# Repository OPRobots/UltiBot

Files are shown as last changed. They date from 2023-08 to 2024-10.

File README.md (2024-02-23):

# UltiBot

Robot de Minisumo con 6 sensores SHARP GP2Y0E03

<table>
<tr>
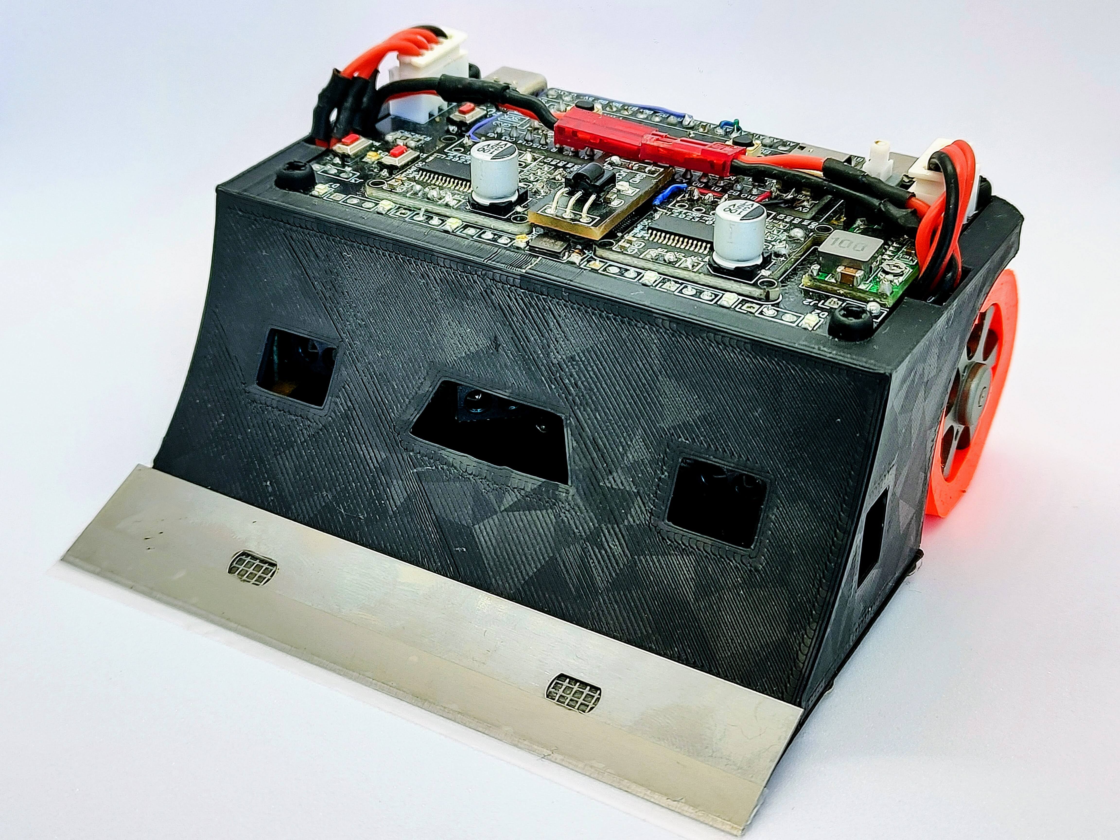
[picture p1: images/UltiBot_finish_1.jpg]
<td  colspan="2">  </td>
</tr>
<tr>
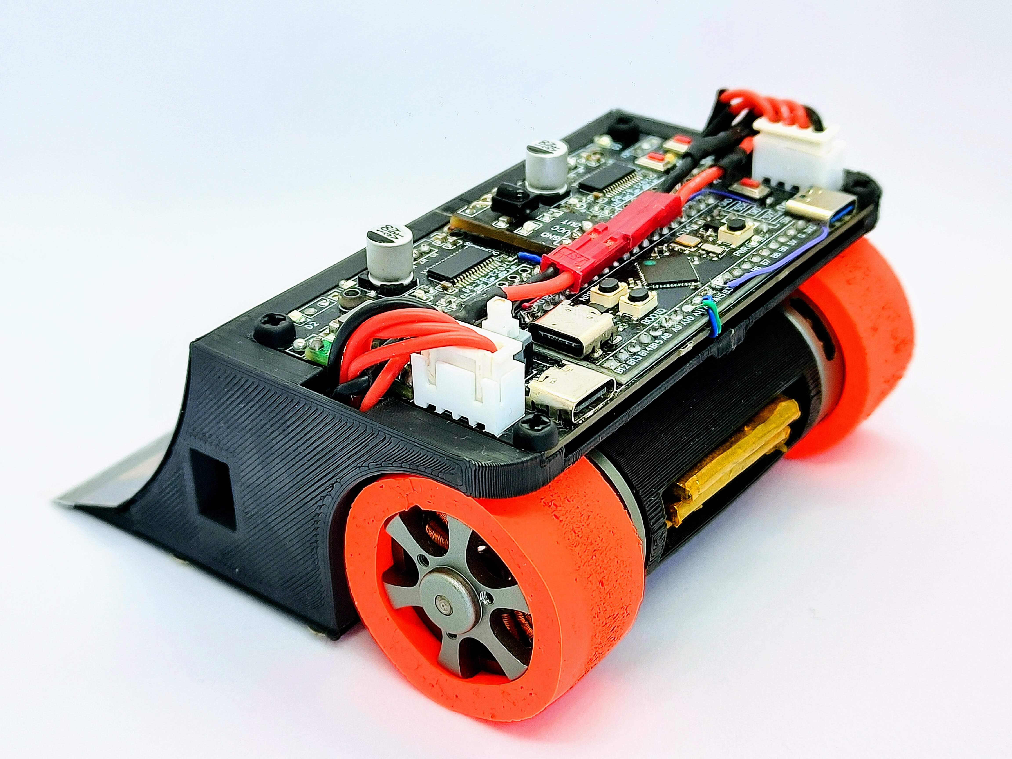
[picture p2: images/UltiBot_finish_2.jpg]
<td>  </td>
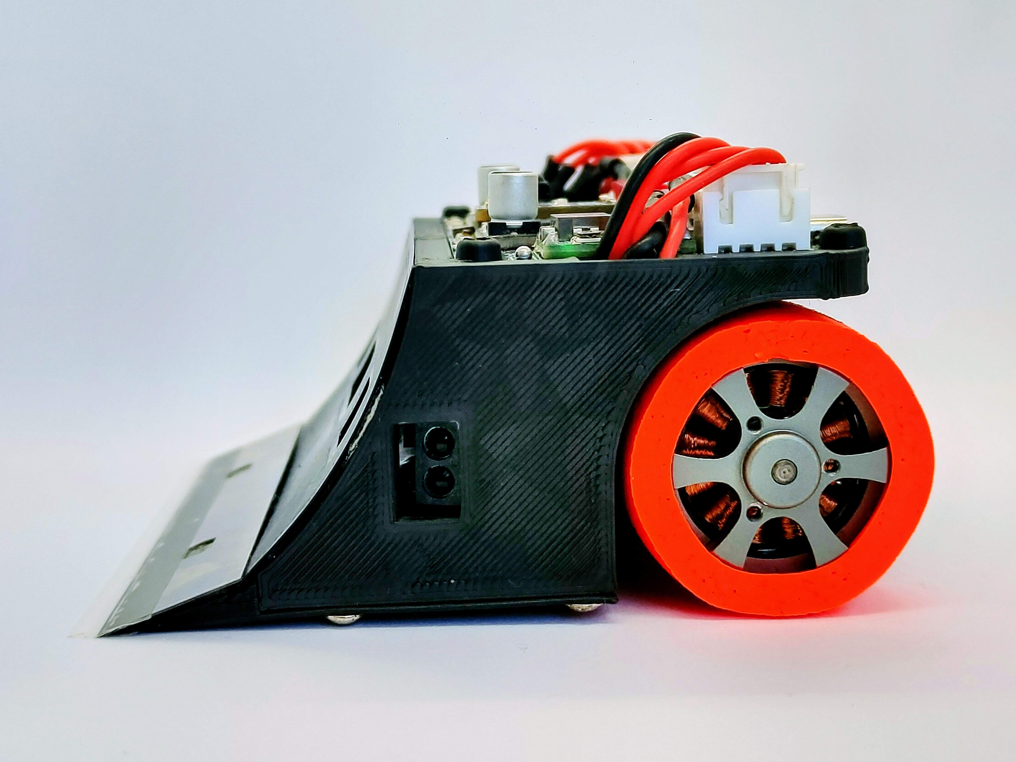
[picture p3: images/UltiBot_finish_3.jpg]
<td>  </td>
</tr>
</table>

## Hardware
- STM32F401CCU6 (Principal) Y STM32F103C8T6 (FOC)
- 2x SimleFOCMini
- 2x Motores gimbal 12v 80T
- 2xLiPo 3S ~180 mAh
- 6x Sensores SHARP GP2Y0E03
- 2x Sensores QRE1113
- Ruedas JSUMO JS2622
- Chasis impreso en PLA

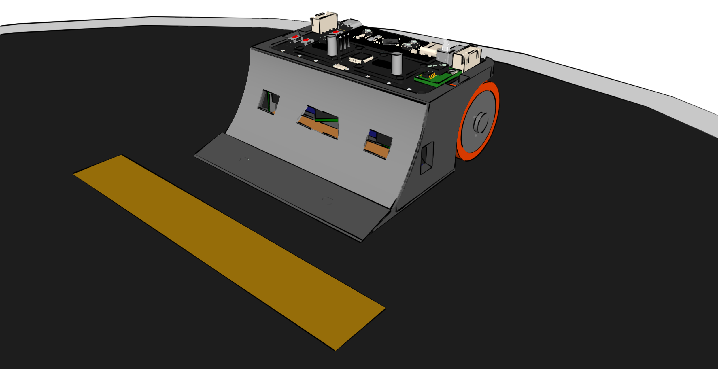
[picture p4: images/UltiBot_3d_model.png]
UltiBot Chasis UltiBot - Chasis


## Software
- Programado con VSCode y PlatformIO
- Disponible programa con estrategias básicas

## KiCAD

### PCB UltiBot v1.0
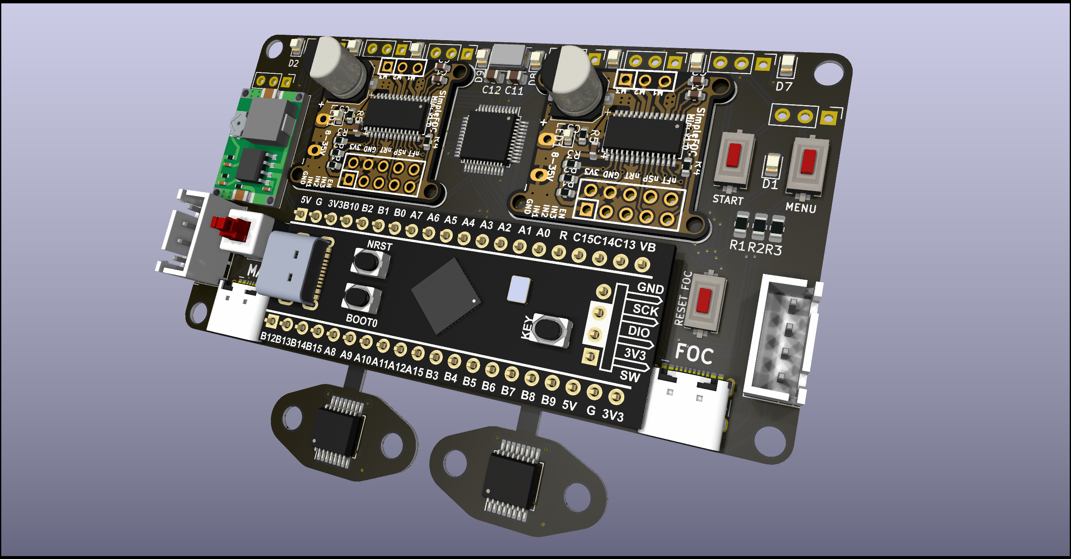
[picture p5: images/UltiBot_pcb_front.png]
UltiBot PCB Front UltiBot - Chasis
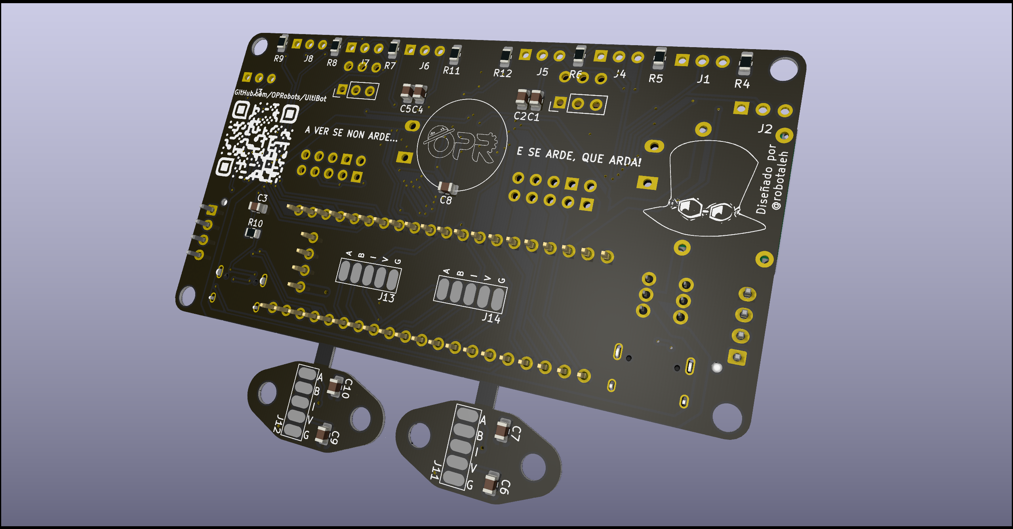
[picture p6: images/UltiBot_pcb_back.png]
UltiBot PCB Back UltiBot - Chasis


### Librerías

Las librerías necesarias para este proyecto se encuentran en [OPRobots/KiCADLibraries](https://github.com/OPRobots/KiCADLibraries)

La estructura tiene que quedar de la siguiente forma:

```bash
└── kicad_project
    └── custom_libraries
        ├── custom_footprints
        │   ├── *.kicad_mod
        │   └── ...
        └── custom_symbols.kicad_sym
```

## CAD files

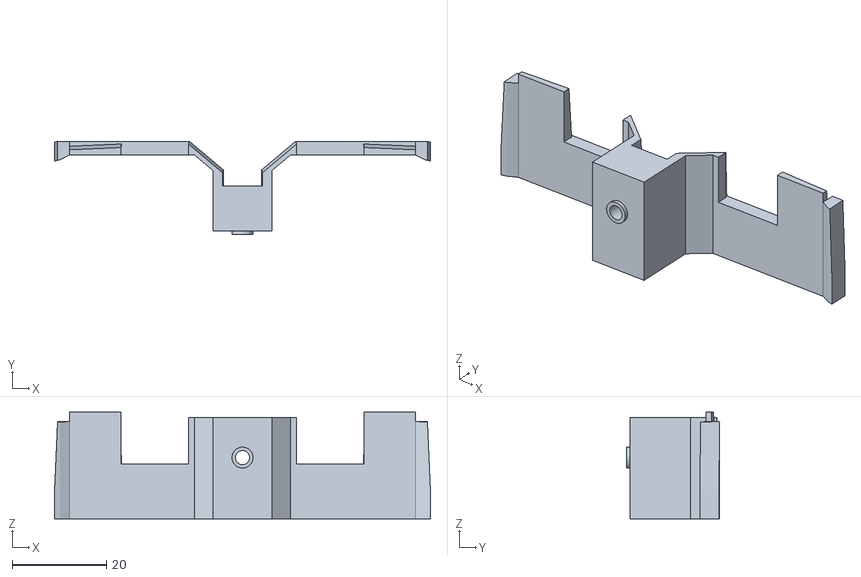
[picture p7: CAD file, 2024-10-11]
3d_model/stl_files/sensor_v2.stl
79.8 x 19.8 x 22.7

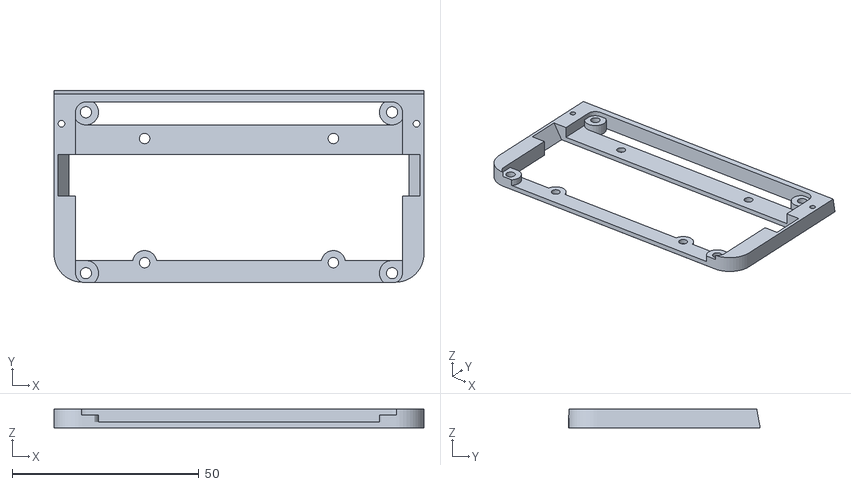
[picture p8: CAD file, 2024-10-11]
3d_model/stl_files/top_v2.stl
99.0 x 51.2 x 5.00

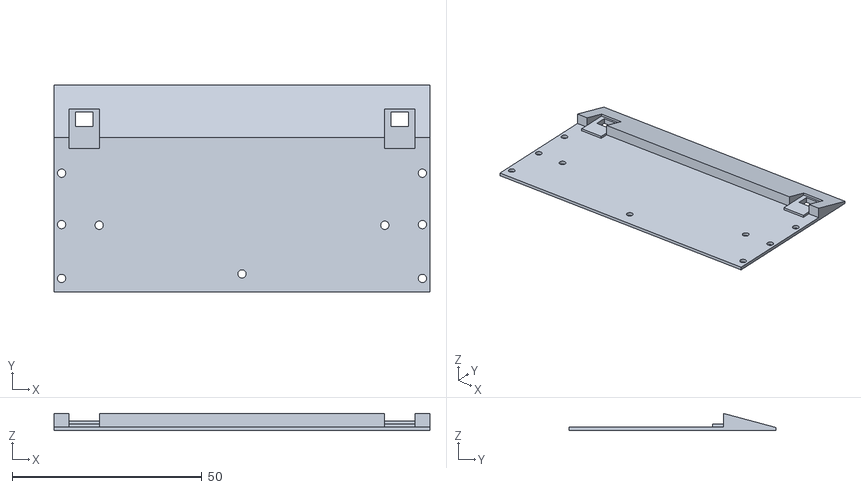
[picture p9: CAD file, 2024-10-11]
3d_model/stl_files/base_v2.stl
99.0 x 54.6 x 4.52

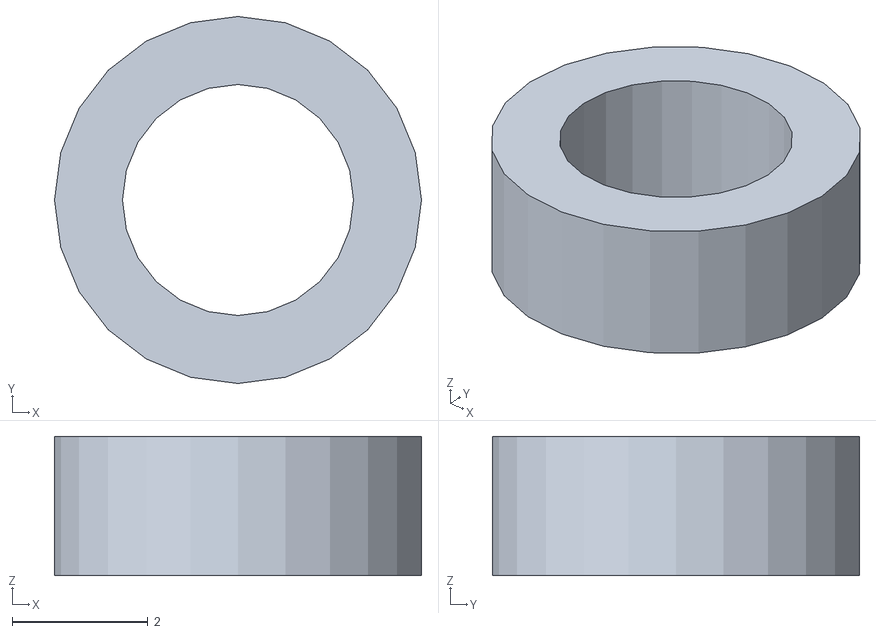
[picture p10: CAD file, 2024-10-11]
3d_model/stl_files/spacer_v2.stl
5.40 x 5.40 x 2.05

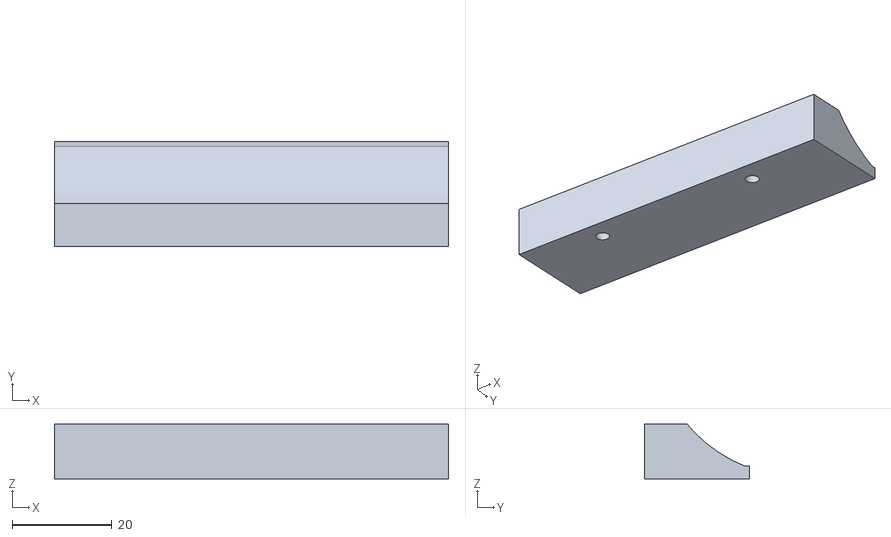
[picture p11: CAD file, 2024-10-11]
3d_model/stl_files/molde_plomo.stl
79.0 x 21.0 x 11.0

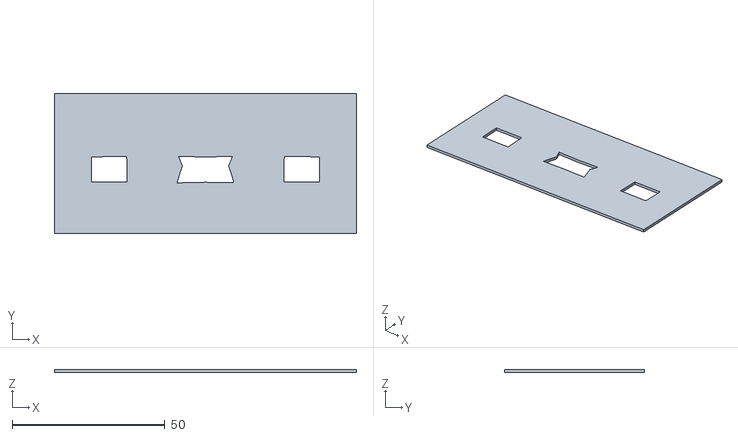
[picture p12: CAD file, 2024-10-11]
3d_model/stl_files/ramp_v2.stl
99.0 x 45.8 x 1.00

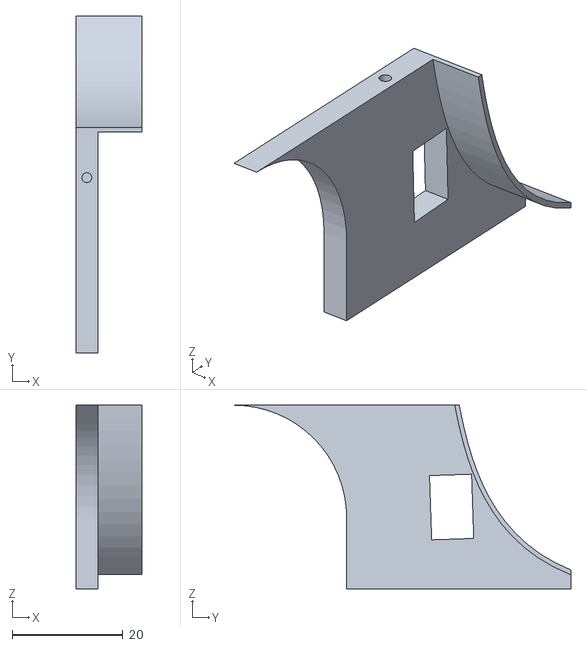
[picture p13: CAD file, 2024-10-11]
3d_model/stl_files/side_v2.stl
12.0 x 60.9 x 33.1

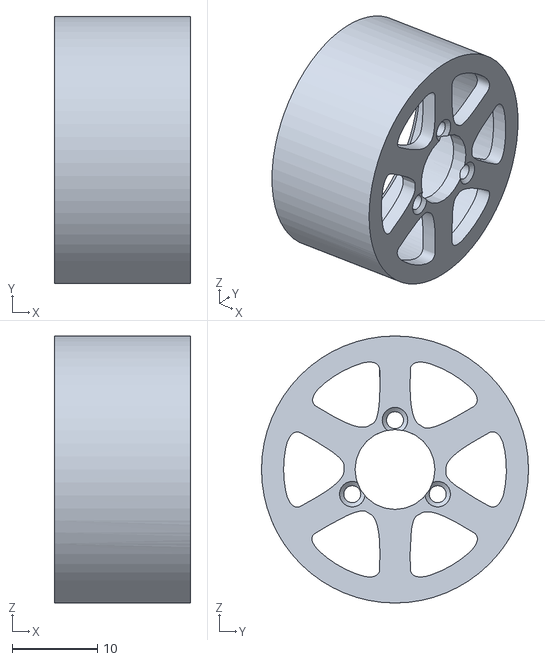
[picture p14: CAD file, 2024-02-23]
3d_model/stl_files/wheel_v2.stl
16.0 x 31.4 x 31.4

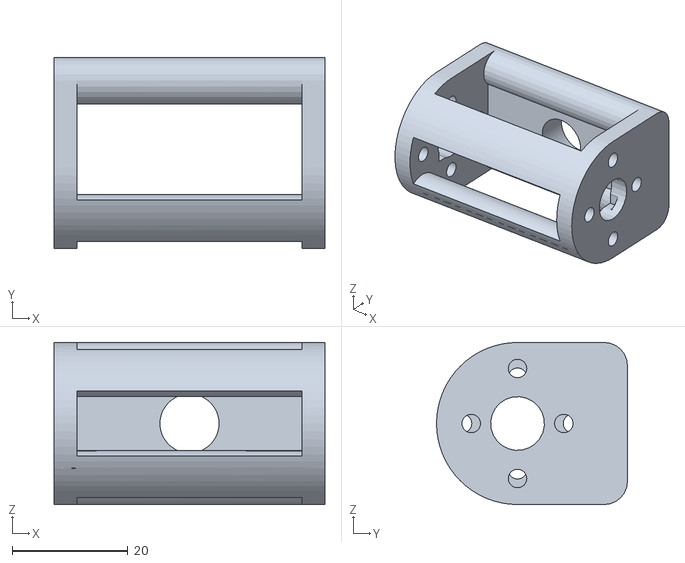
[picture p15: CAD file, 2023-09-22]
3d_model/stl_files/motors.stl
46.8 x 33.0 x 28.0

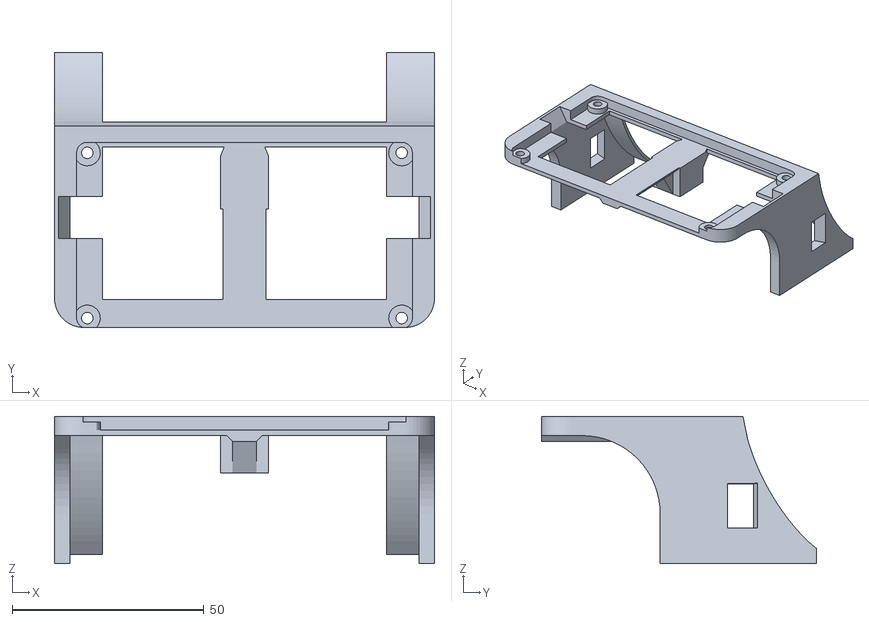
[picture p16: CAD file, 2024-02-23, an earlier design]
3d_model/stl_files/top.stl
99.0 x 71.6 x 38.3

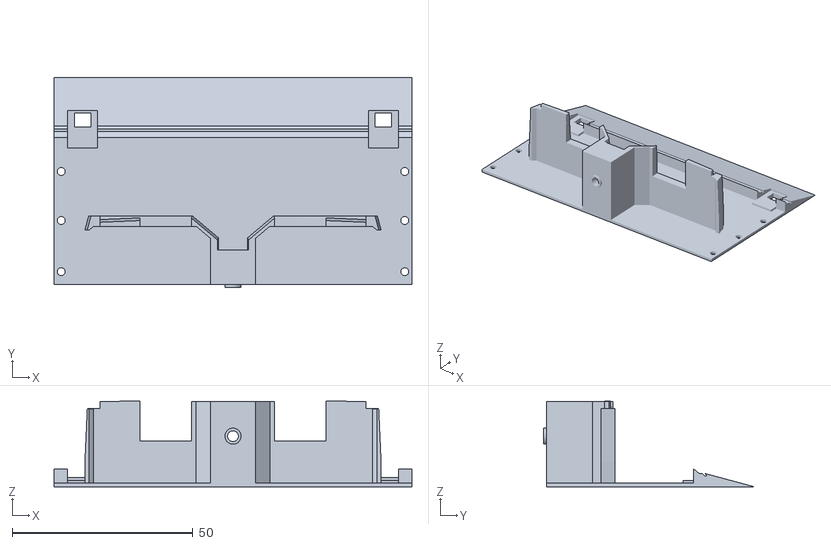
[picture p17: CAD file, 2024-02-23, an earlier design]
3d_model/stl_files/base.stl
99.0 x 58.0 x 23.7

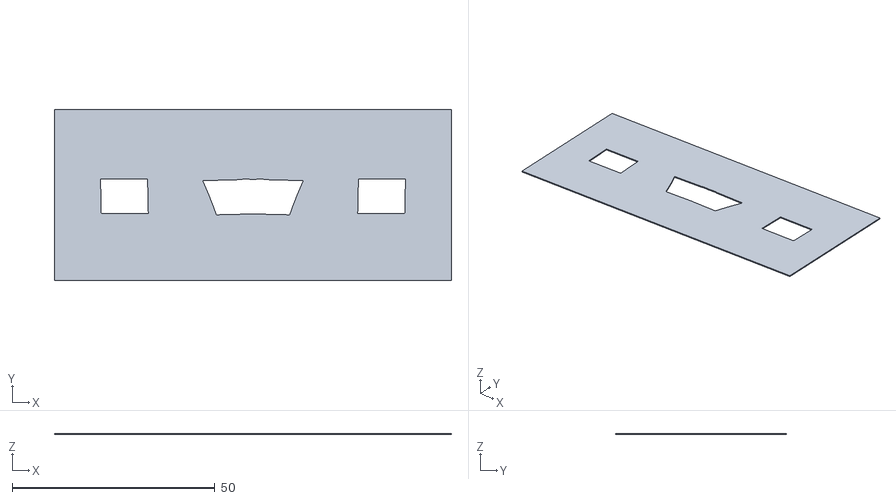
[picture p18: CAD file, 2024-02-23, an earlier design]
3d_model/stl_files/ramp.stl
98.0 x 42.2 x 0.302

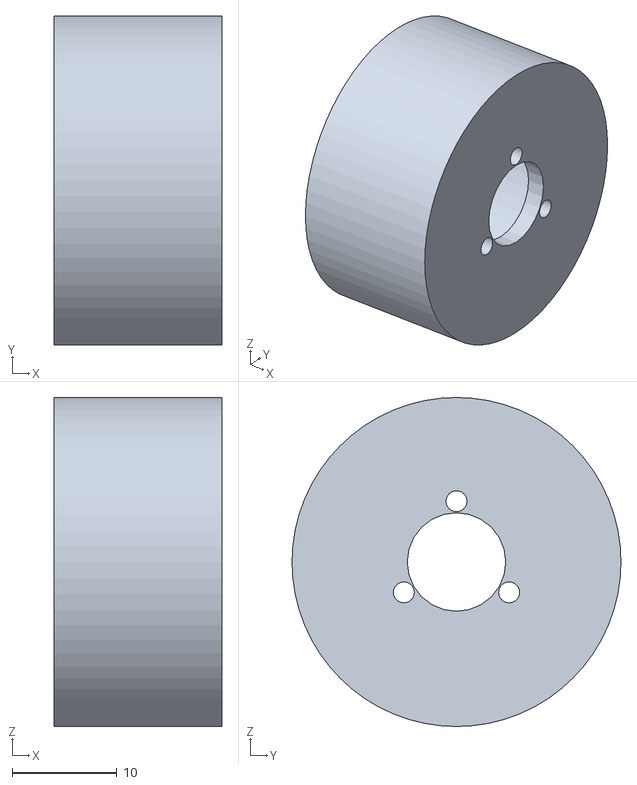
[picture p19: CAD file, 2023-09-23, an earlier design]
3d_model/stl_files/wheel.stl
16.0 x 31.4 x 31.4

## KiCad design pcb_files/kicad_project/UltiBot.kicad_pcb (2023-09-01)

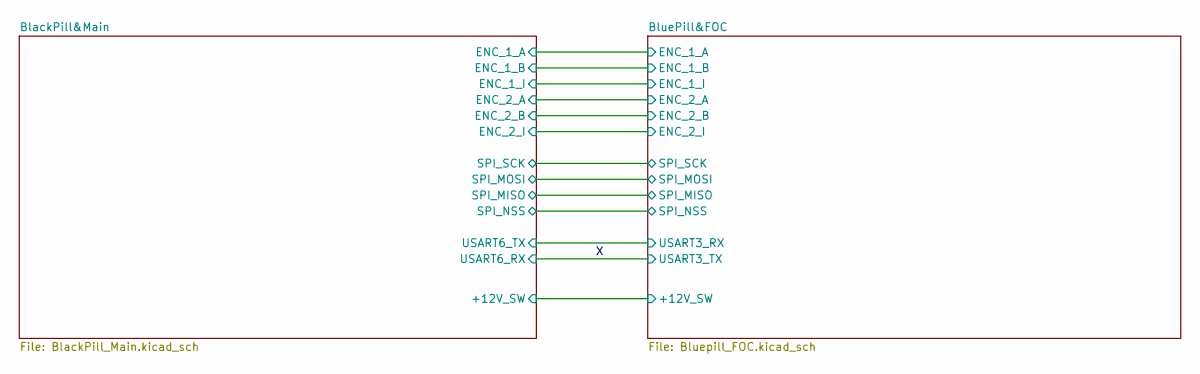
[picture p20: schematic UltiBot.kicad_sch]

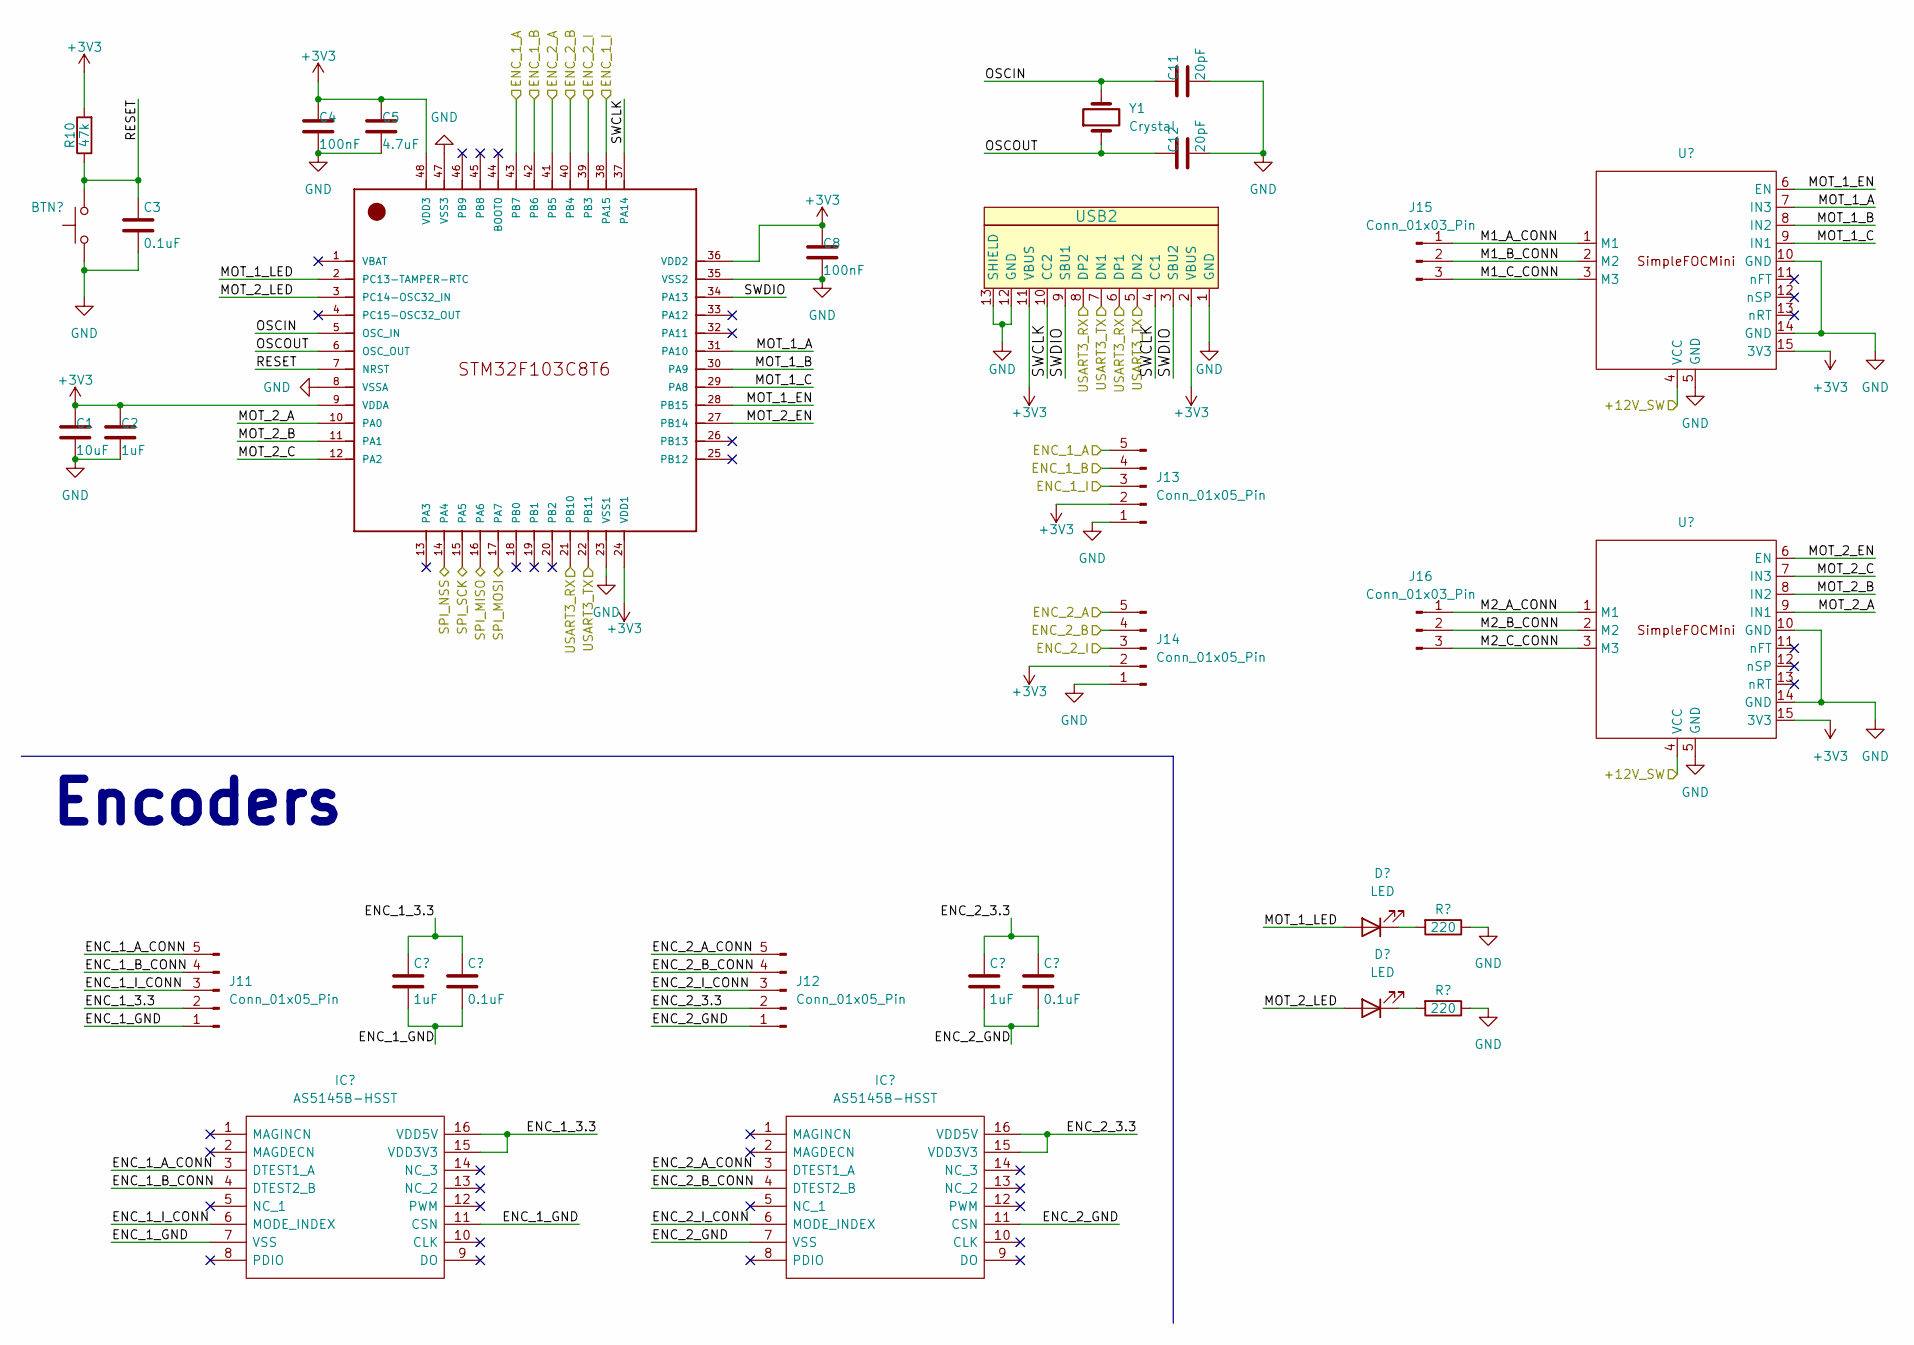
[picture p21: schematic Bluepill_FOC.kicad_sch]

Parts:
BTN3: SW_SPST_EVQPE1
C1: 10uF; C_0805_2012Metric
C2, C6, C9: 1uF; C_0805_2012Metric
C3, C7, C10: 0.1uF; C_0805_2012Metric
C4, C8: 100nF; C_0805_2012Metric
C5: 4.7uF; C_0805_2012Metric
C11, C12: 20pF; C_0805_2012Metric
D8, D9: LED; LED_0805_2012Metric
IC1, IC2: AS5145B-HSST; SSOP-16_5.3x6.2mm_P0.65mm
J11, J12, J13, J14: Conn_01x05_Pin; 1x05 Pad
J15, J16: Conn_01x03_Pin; PinHeader_1x03_P2.54mm_Vertical
R10: 47k; R_0805_2012Metric
R11, R12: 220; R_0805_2012Metric_Pad1.20x1.40mm_HandSolder
U2: BluePill; LQFP-48_7x7mm_P0.5mm
U3, U4: SimpleFOCMini
USB2: USB-C ST-Link USART
Y1: Crystal; Crystal_SMD_5032-2Pin_5.0x3.2mm

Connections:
+3V3: C1.1, C2.1, C4.1, C5.1, C8.1, J13.2, J14.2, R10.2, U2.9 (VDDA), U2.24 (VDD1), U2.36 (VDD2), U2.48 (VDD3), U3.15 (3V3), U4.15 (3V3), USB2.2 (VBUS), USB2.11 (VBUS); also elsewhere on the board
/BlackPill&Main/+12V_SW: U3.4 (VCC), U4.4 (VCC); also elsewhere on the board
/BlackPill&Main/ENC_1_A: J13.5, U2.43 (PB7); also elsewhere on the board
/BlackPill&Main/ENC_1_B: J13.4, U2.42 (PB6); also elsewhere on the board
/BlackPill&Main/ENC_1_I: J13.3, U2.38 (PA15); also elsewhere on the board
/BlackPill&Main/ENC_2_A: J14.5, U2.41 (PB5); also elsewhere on the board
/BlackPill&Main/ENC_2_B: J14.4, U2.40 (PB4); also elsewhere on the board
/BlackPill&Main/ENC_2_I: J14.3, U2.39 (PB3); also elsewhere on the board
/BlackPill&Main/SPI_MISO: U2.16 (PA6); also elsewhere on the board
/BlackPill&Main/SPI_MOSI: U2.17 (PA7); also elsewhere on the board
/BlackPill&Main/SPI_NSS: U2.14 (PA4); also elsewhere on the board
/BlackPill&Main/SPI_SCK: U2.15 (PA5); also elsewhere on the board
/BlackPill&Main/USART6_RX: U2.22 (PB11), USB2.5 (DN2), USB2.7 (DN1); also elsewhere on the board
/BlackPill&Main/USART6_TX: U2.21 (PB10), USB2.6 (DP1), USB2.8 (DP2); also elsewhere on the board
/BluePill&FOC/ENC_1_3.3: C6.1, C7.1, IC1.15 (VDD3V3), IC1.16 (VDD5V), J11.2
/BluePill&FOC/ENC_1_A_CONN: IC1.3 (DTEST1_A), J11.5
/BluePill&FOC/ENC_1_B_CONN: IC1.4 (DTEST2_B), J11.4
/BluePill&FOC/ENC_1_GND: C6.2, C7.2, IC1.7 (VSS), IC1.11 (CSN), J11.1
/BluePill&FOC/ENC_1_I_CONN: IC1.6 (MODE_INDEX), J11.3
/BluePill&FOC/ENC_2_3.3: C9.1, C10.1, IC2.15 (VDD3V3), IC2.16 (VDD5V), J12.2
/BluePill&FOC/ENC_2_A_CONN: IC2.3 (DTEST1_A), J12.5
/BluePill&FOC/ENC_2_B_CONN: IC2.4 (DTEST2_B), J12.4
/BluePill&FOC/ENC_2_GND: C9.2, C10.2, IC2.7 (VSS), IC2.11 (CSN), J12.1
/BluePill&FOC/ENC_2_I_CONN: IC2.6 (MODE_INDEX), J12.3
/BluePill&FOC/M1_A_CONN: J15.1, U3.1 (M1)
/BluePill&FOC/M1_B_CONN: J15.2, U3.2 (M2)
/BluePill&FOC/M1_C_CONN: J15.3, U3.3 (M3)
/BluePill&FOC/M2_A_CONN: J16.1, U4.1 (M1)
/BluePill&FOC/M2_B_CONN: J16.2, U4.2 (M2)
/BluePill&FOC/M2_C_CONN: J16.3, U4.3 (M3)
/BluePill&FOC/MOT_1_A: U2.31 (PA10), U3.7 (IN3)
/BluePill&FOC/MOT_1_B: U2.30 (PA9), U3.8 (IN2)
/BluePill&FOC/MOT_1_C: U2.29 (PA8), U3.9 (IN1)
/BluePill&FOC/MOT_1_EN: U2.28 (PB15), U3.6 (EN)
/BluePill&FOC/MOT_1_LED: D8.2 (A), U2.2 (PC13-TAMPER-RTC)
/BluePill&FOC/MOT_2_A: U2.10 (PA0), U4.9 (IN1)
/BluePill&FOC/MOT_2_B: U2.11 (PA1), U4.8 (IN2)
/BluePill&FOC/MOT_2_C: U2.12 (PA2), U4.7 (IN3)
/BluePill&FOC/MOT_2_EN: U2.27 (PB14), U4.6 (EN)
/BluePill&FOC/MOT_2_LED: D9.2 (A), U2.3 (PC14-OSC32_IN)
/BluePill&FOC/OSCIN: C11.1, U2.5 (OSC_IN), Y1.2
/BluePill&FOC/OSCOUT: C12.1, U2.6 (OSC_OUT), Y1.1
/BluePill&FOC/RESET: BTN3.2, C3.1, R10.1, U2.7 (NRST)
/BluePill&FOC/SWCLK: U2.37 (PA14), USB2.4 (CC1), USB2.10 (CC2)
/BluePill&FOC/SWDIO: U2.34 (PA13), USB2.3 (SBU2), USB2.9 (SBU1)
GND: BTN3.1, C1.2, C2.2, C3.2, C4.2, C5.2, C8.2, C11.2, C12.2, J13.1, J14.1, R11.1, R12.1, U2.8 (VSSA), U2.23 (VSS1), U2.35 (VSS2), U2.47 (VSS3), U3.5 (GND), U3.10 (GND), U3.14 (GND), U4.5 (GND), U4.10 (GND), U4.14 (GND), USB2.1 (GND), USB2.12 (GND), USB2.13 (SHIELD); also elsewhere on the board
unnamed: D8.1 (K), R11.2
unnamed: D9.1 (K), R12.2

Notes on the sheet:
Encoders

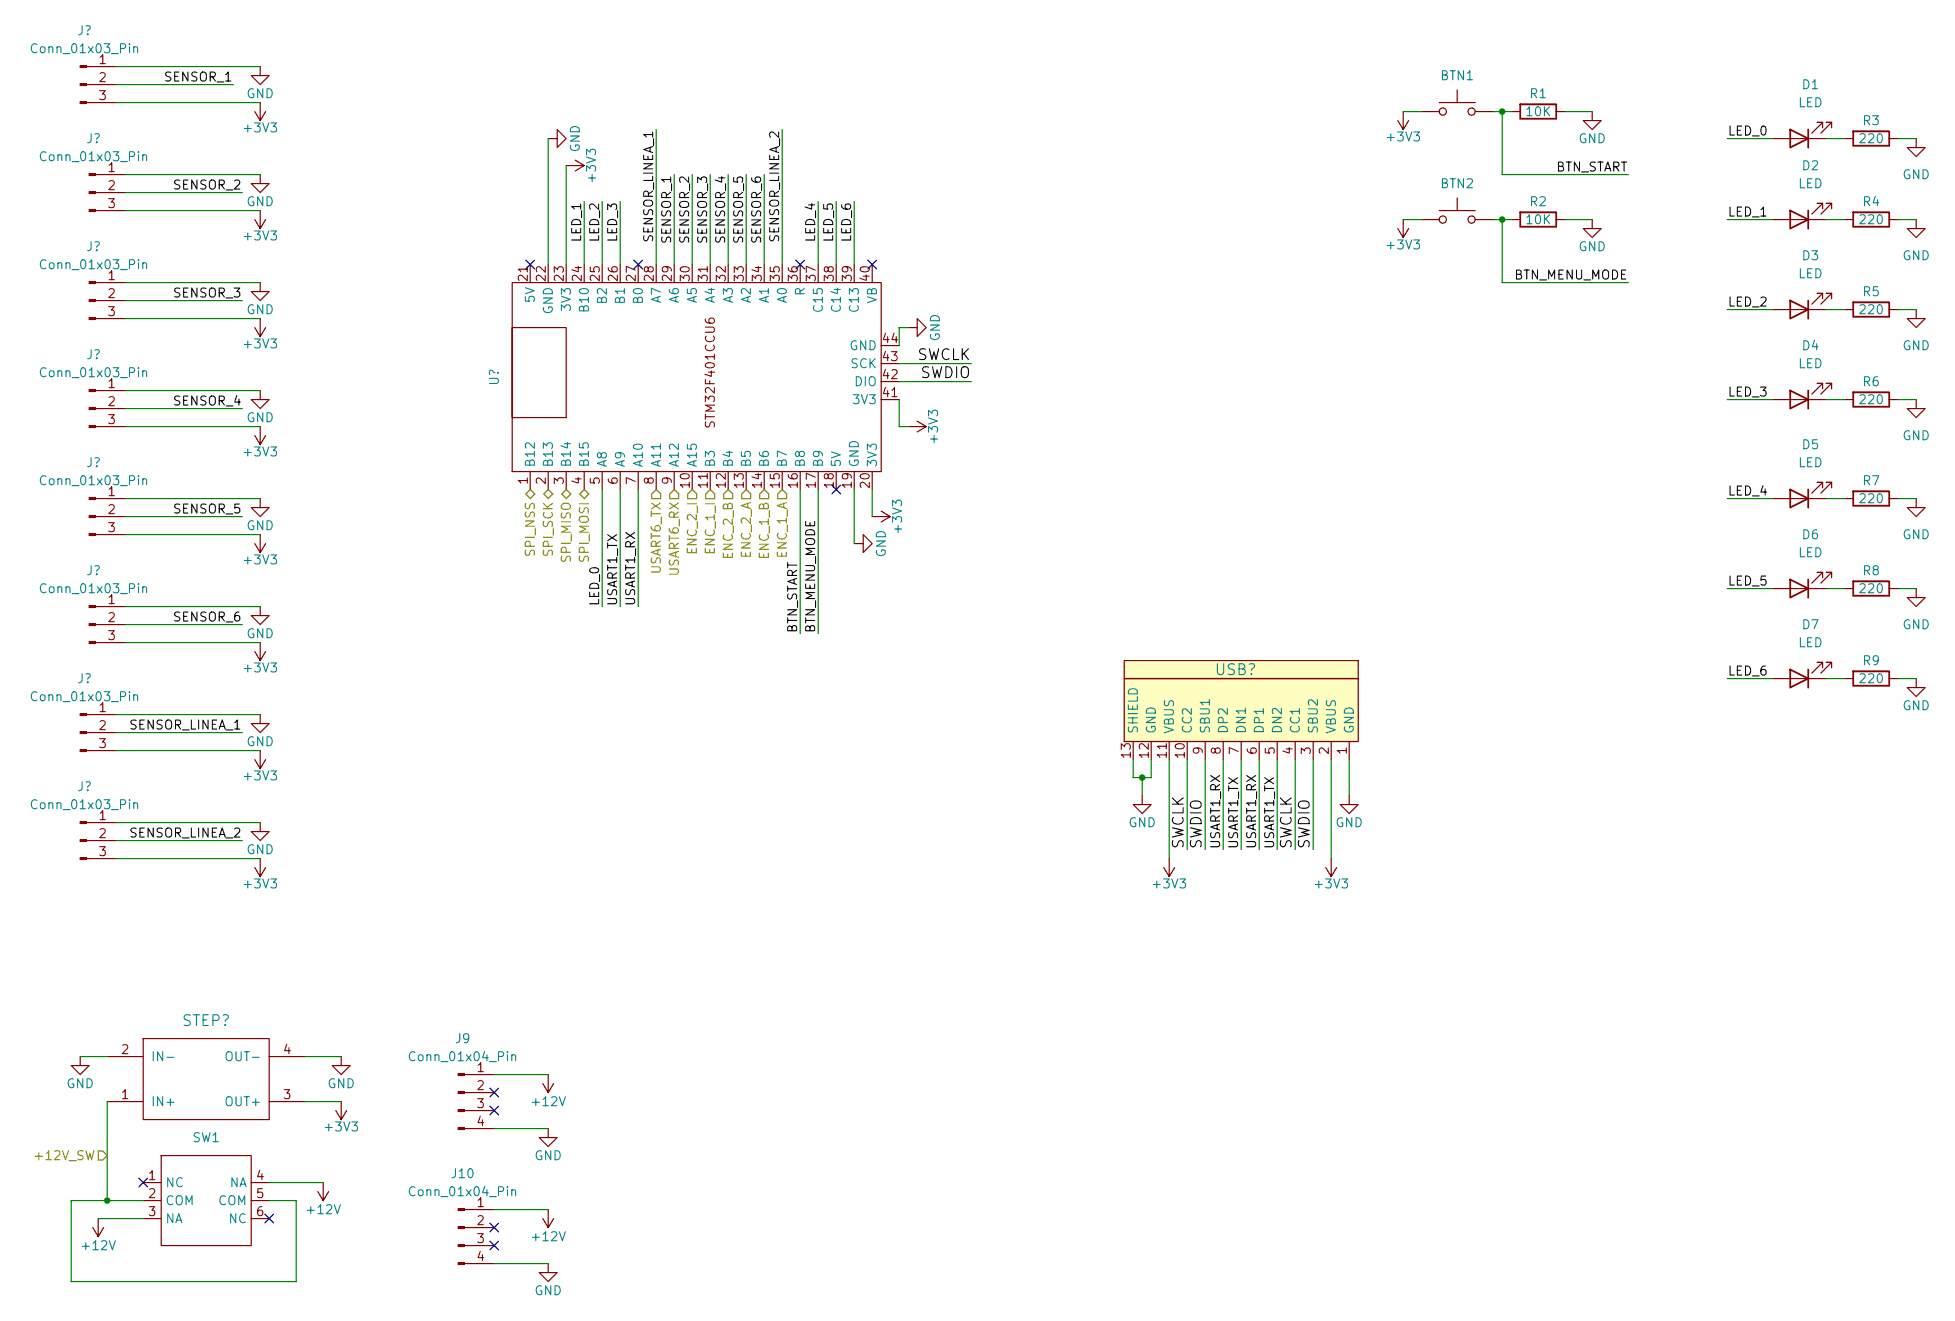
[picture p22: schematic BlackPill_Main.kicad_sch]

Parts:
BTN1, BTN2: SW_SPST_EVQPE1
D1, D2, D3, D4, D5, D6, D7: LED; LED_0805_2012Metric
J1, J2, J3, J4, J5, J6, J7, J8: Conn_01x03_Pin; PinHeader_1x03_P2.54mm_Vertical
J9, J10: Conn_01x04_Pin; JST_XH_B4B-XH-AM_1x04_P2.50mm_Vertical
R1, R2: 10K; R_0805_2012Metric_Pad1.20x1.40mm_HandSolder
R3, R4, R5, R6, R7, R8, R9: 220; R_0805_2012Metric_Pad1.20x1.40mm_HandSolder
STEP1: Mini360
SW1: Switch6P
U1: BlackPill_STM32F401
USB1: USB-C ST-Link USART

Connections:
+3V3: BTN1.1, BTN2.1, J1.3, J2.3, J3.3, J4.3, J5.3, J6.3, J7.3, J8.3, STEP1.3 (OUT+), U1.20 (3V3), U1.23 (3V3), U1.41 (3V3), USB1.2 (VBUS), USB1.11 (VBUS); also elsewhere on the board
+12V: J9.1, J10.1, SW1.3 (NA), SW1.4 (NA); also elsewhere on the board
/BlackPill&Main/+12V_SW: STEP1.1 (IN+), SW1.2 (COM), SW1.5 (COM); also elsewhere on the board
/BlackPill&Main/BTN_MENU_MODE: BTN2.2, R2.2, U1.17 (B9)
/BlackPill&Main/BTN_START: BTN1.2, R1.2, U1.16 (B8)
/BlackPill&Main/ENC_1_A: U1.15 (B7); also elsewhere on the board
/BlackPill&Main/ENC_1_B: U1.14 (B6); also elsewhere on the board
/BlackPill&Main/ENC_1_I: U1.11 (B3); also elsewhere on the board
/BlackPill&Main/ENC_2_A: U1.13 (B5); also elsewhere on the board
/BlackPill&Main/ENC_2_B: U1.12 (B4); also elsewhere on the board
/BlackPill&Main/ENC_2_I: U1.10 (A15); also elsewhere on the board
/BlackPill&Main/LED_0: D1.2 (A), U1.5 (A8)
/BlackPill&Main/LED_1: D2.2 (A), U1.24 (B10)
/BlackPill&Main/LED_2: D3.2 (A), U1.25 (B2)
/BlackPill&Main/LED_3: D4.2 (A), U1.26 (B1)
/BlackPill&Main/LED_4: D5.2 (A), U1.37 (C15)
/BlackPill&Main/LED_5: D6.2 (A), U1.38 (C14)
/BlackPill&Main/LED_6: D7.2 (A), U1.39 (C13)
/BlackPill&Main/SENSOR_1: J1.2, U1.29 (A6)
/BlackPill&Main/SENSOR_2: J4.2, U1.30 (A5)
/BlackPill&Main/SENSOR_3: J5.2, U1.31 (A4)
/BlackPill&Main/SENSOR_4: J6.2, U1.32 (A3)
/BlackPill&Main/SENSOR_5: J7.2, U1.33 (A2)
/BlackPill&Main/SENSOR_6: J8.2, U1.34 (A1)
/BlackPill&Main/SENSOR_LINEA_1: J2.2, U1.28 (A7)
/BlackPill&Main/SENSOR_LINEA_2: J3.2, U1.35 (A0)
/BlackPill&Main/SPI_MISO: U1.3 (B14); also elsewhere on the board
/BlackPill&Main/SPI_MOSI: U1.4 (B15); also elsewhere on the board
/BlackPill&Main/SPI_NSS: U1.1 (B12); also elsewhere on the board
/BlackPill&Main/SPI_SCK: U1.2 (B13); also elsewhere on the board
/BlackPill&Main/SWCLK: U1.43 (SCK), USB1.4 (CC1), USB1.10 (CC2)
/BlackPill&Main/SWDIO: U1.42 (DIO), USB1.3 (SBU2), USB1.9 (SBU1)
/BlackPill&Main/USART1_RX: U1.7 (A10), USB1.6 (DP1), USB1.8 (DP2)
/BlackPill&Main/USART1_TX: U1.6 (A9), USB1.5 (DN2), USB1.7 (DN1)
/BlackPill&Main/USART6_RX: U1.9 (A12); also elsewhere on the board
/BlackPill&Main/USART6_TX: U1.8 (A11); also elsewhere on the board
GND: J1.1, J2.1, J3.1, J4.1, J5.1, J6.1, J7.1, J8.1, J9.4, J10.4, R1.1, R2.1, R3.1, R4.1, R5.1, R6.1, R7.1, R8.1, R9.1, STEP1.2 (IN-), STEP1.4 (OUT-), U1.19 (GND), U1.22 (GND), U1.44 (GND), USB1.1 (GND), USB1.12 (GND), USB1.13 (SHIELD); also elsewhere on the board
unnamed: D1.1 (K), R3.2
unnamed: D2.1 (K), R4.2
unnamed: D3.1 (K), R5.2
unnamed: D4.1 (K), R6.2
unnamed: D5.1 (K), R7.2
unnamed: D6.1 (K), R8.2
unnamed: D7.1 (K), R9.2

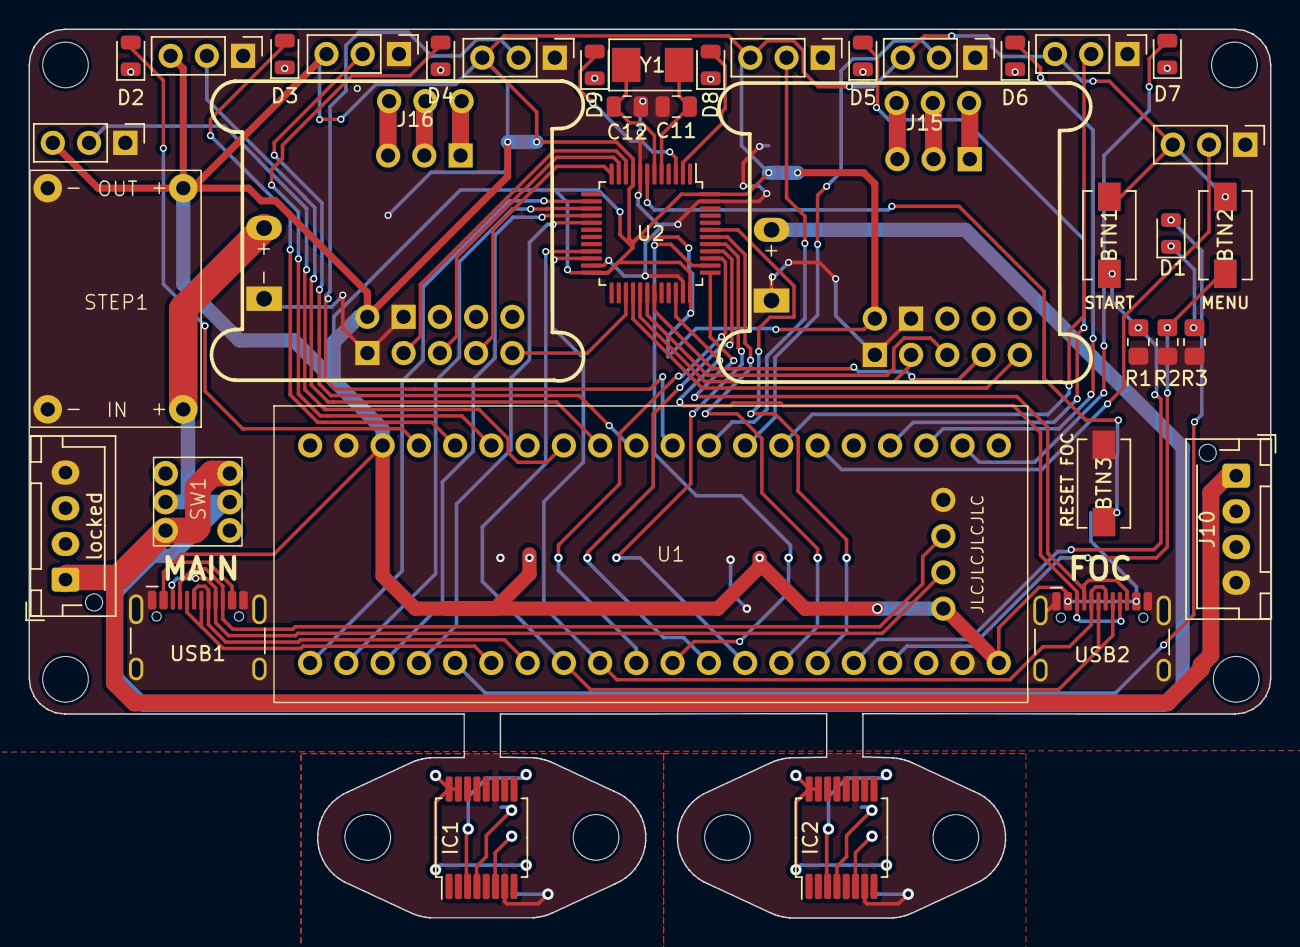
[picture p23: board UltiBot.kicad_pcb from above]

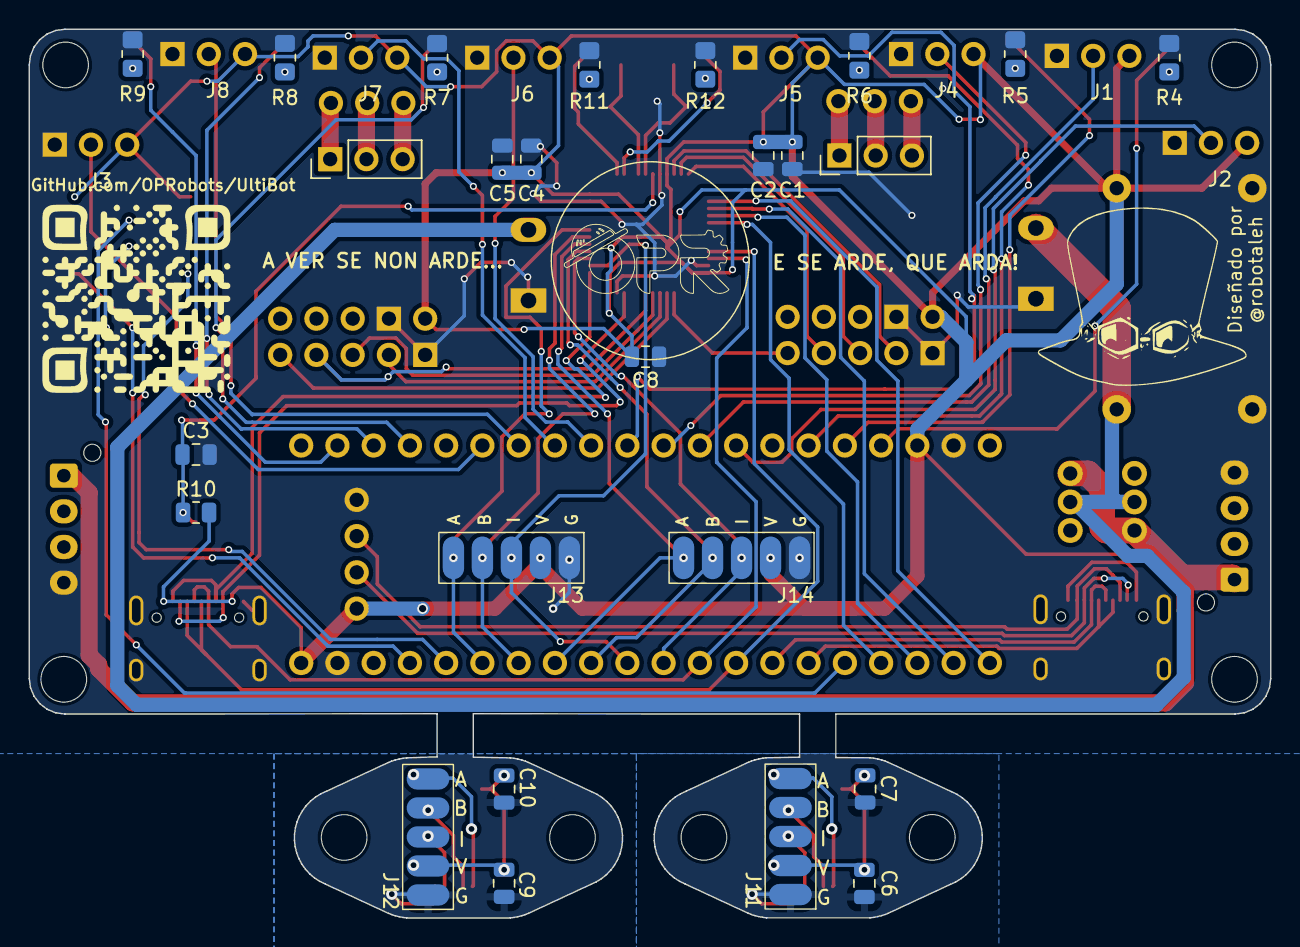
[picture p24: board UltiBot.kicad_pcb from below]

Board: 2 copper layers, 87.0 x 62.3 mm, 63 parts (25 on the bottom side), 77 nets.

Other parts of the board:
locked: Conn_01x04_Pin; JST - XH - Thru (V) - 4Pin - 2.54mm

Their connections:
+12V: locked.1; also elsewhere on the board
GND: locked.4; also elsewhere on the board

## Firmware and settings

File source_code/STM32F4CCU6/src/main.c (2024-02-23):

#include "command.h"
#include "config.h"
#include "control.h"
#include "debug.h"
#include "delay.h"
#include "leds.h"
#include "menu.h"
#include "motors.h"
#include "sensors.h"
#include "setup.h"
#include "usart.h"
#include "eeprom.h"
#include "rc5.h"

void sys_tick_handler(void) {
  clock_tick();
  update_sensors_readings();
}

int main(void) {
  setup();
  eeprom_load();
  rc5_init();

  while (true) {
    // debug_sensors_leds();
    // debug_sensors_raw();
    // // debug_sensors_position();
    // // printf("%d - %d\n", get_sensor_digital(SENSOR_LINE_LEFT), get_sensor_digital(SENSOR_LINE_RIGHT));
    // // // // // printf("%d\n", get_sensor_filtered(SENSOR_FRONT_LEFT));
    // // delay(25);

    // // send_command(CMD_MOTOR_SPEED_RIGHT, 40);
    // // send_command(CMD_MOTOR_SPEED_LEFT, 40);
    // // send_command(CMD_MOTOR_ENABLE, 0);
    // // delay(15000);
    // // send_command(CMD_MOTOR_SPEED_RIGHT, 0);
    // // send_command(CMD_MOTOR_SPEED_LEFT, 0);
    // // send_command(CMD_MOTOR_DISABLE, 0);
    // // delay(2000);

    // // if (get_start_btn()) {
    // //   send_command(CMD_MOTOR_DISABLE, 0);
    // //   send_command(CMD_MOTOR_SPEED_RIGHT, 40);
    // //   send_command(CMD_MOTOR_SPEED_LEFT, 40);
    // // } else {
    // //   send_command(CMD_MOTOR_ENABLE, 0);
    // //   send_command(CMD_MOTOR_SPEED_RIGHT, 20);
    // //   send_command(CMD_MOTOR_SPEED_LEFT, 20);
    // // }
    // // printf("pato\n");
    // // printf("%ld\n", get_us_counter());
    // delay(100);

    // continue;

    if (!is_competicion_iniciada() && !is_competicion_iniciando()) {
      check_menu_button();
      // debug_sensors_leds();
      if (get_start_btn()) {
        set_sensor_led(false);
        set_menu_led(false);
        while (get_start_btn()) {
          set_sensor_led_waiting(100);
        }
        set_competicion_iniciando(true);
      }
    } else if (is_competicion_iniciando()) {
      uint32_t millisInicio = get_clock_ticks();
      while (get_clock_ticks() < (millisInicio + get_start_millis()) && is_competicion_iniciando()) {
        set_sensor_led_starting(millisInicio);
      }
      if (is_competicion_iniciando()) {
        set_sensor_led(false);
        set_competicion_iniciada(true);
        send_command(CMD_MOTOR_ENABLE, 0);
      }
    } else {
      debug_sensors_leds();
      control_main_loop();
    }
  }
  return 0;
}

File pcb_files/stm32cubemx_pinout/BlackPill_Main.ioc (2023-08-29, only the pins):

Mcu.UserName=STM32F401CCUx
PA0-WKUP.Signal=ADCx_IN0
PA1.Signal=ADCx_IN1
PA10.Signal=USART1_RX
PA11.Signal=USART6_TX
PA12.Signal=USART6_RX
PA13.Signal=SYS_JTMS-SWDIO
PA14.Signal=SYS_JTCK-SWCLK
PA15.GPIO_Label=ENC_2_I
PA15.Signal=GPXTI15
PA2.Signal=ADCx_IN2
PA3.Signal=ADCx_IN3
PA4.Signal=ADCx_IN4
PA5.Signal=ADCx_IN5
PA6.Signal=ADCx_IN6
PA7.Signal=ADCx_IN7
PA8.GPIO_Label=LED_5
PA8.Signal=GPIO_Output
PA9.Signal=USART1_TX
PB1.GPIO_Label=LED_6
PB1.Signal=GPIO_Output
PB10.GPIO_Label=LED_4
PB10.Signal=GPIO_Output
PB12.Signal=SPI2_NSS
PB13.Signal=SPI2_SCK
PB14.Signal=SPI2_MISO
PB15.Signal=SPI2_MOSI
PB2.GPIO_Label=LED_3
PB2.Signal=GPIO_Output
PB3.GPIO_Label=ENC_1_I
PB3.Signal=GPXTI3
PB4.GPIO_Label=ENC_2_B
PB4.Signal=S_TIM3_CH1
PB5.GPIO_Label=ENC_2_A
PB5.Signal=S_TIM3_CH2
PB6.GPIO_Label=ENC_1_B
PB6.Signal=S_TIM4_CH1
PB7.GPIO_Label=ENC_1_A
PB7.Signal=S_TIM4_CH2
PB8.GPIO_Label=BTN_START
PB8.Signal=GPIO_Input
PB9.GPIO_Label=BTN_MENU_MODE
PB9.Signal=GPIO_Input
PC13-ANTI_TAMP.GPIO_Label=LED_0
PC13-ANTI_TAMP.Signal=GPIO_Output
PC14-OSC32_IN.GPIO_Label=LED_1
PC14-OSC32_IN.Signal=GPIO_Output
PC15-OSC32_OUT.GPIO_Label=LED_2
PC15-OSC32_OUT.Signal=GPIO_Output

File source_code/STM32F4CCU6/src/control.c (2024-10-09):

#include "control.h"

static bool competicionIniciada = false;
static bool competicionIniciando = false;
static enum STATUS last_state;
static enum STATUS current_state = STATE_OPENING;
static enum OPENINGS current_opening = OPENING_FRONT;
static enum STRATS current_strat = STRAT_PID; // TODO: actualizar estrategia por defecto

static uint32_t current_state_timer = 0;
static uint32_t current_strat_timer = 0;

static uint32_t strat_pid_last_ms = 0;
static int16_t strat_pid_last_error = 0;

static uint32_t strat_steps_last_ms = 0;
static uint16_t strat_steps_count = 0;

static void set_state(enum STATUS state) {
  last_state = current_state;
  current_state = state;
  current_state_timer = get_clock_ticks();
}

static void check_outter_line(void) {
  if (current_state != STATE_KEEPING_INSIDE && (get_sensor_digital(SENSOR_LINE_LEFT) || get_sensor_digital(SENSOR_LINE_RIGHT))) {
    set_state(STATE_KEEPING_INSIDE);
  }
}

static void keeping_inside(void) {
  uint32_t time = get_clock_ticks() - current_state_timer;
  if (time <= 200) {
    set_motors_speed(-TURN_SPEED, -TURN_SPEED);
  } else if (time <= 400 && !is_rival_detected()) {
    set_motors_speed(TURN_SPEED, -TURN_SPEED);
  } else {
    // TODO: comprobar si no hay problemas de referencias al asignar lo mismo que se está modificando justo dentro
    set_state(last_state);
  }
}

static void opening_front(void) {
  set_state(STATE_RUNNING);
}

static void opening_right(void) {
  uint32_t time = get_clock_ticks() - current_state_timer;
  if (time <= 70 || (time <= 140 && !is_rival_detected())) {
    set_motors_speed(80, -80);
  } else {
    // set_motors_speed(0, 0);
    // if (time >= 600) {
    //   send_command(CMD_MOTOR_DISABLE, 0);
    // }
    set_state(STATE_RUNNING);
  }
}

static void opening_right_arc(void) {
  uint32_t time = get_clock_ticks() - current_state_timer;
  if (time <= 190 || (time <= 380 && !is_rival_detected())) {
    set_motors_speed(90, 40);
  } else if (time <= 190 + 120 || (time <= 380 + 240 && !is_rival_detected())) {
    set_motors_speed(-80, 80);
  } else {
    // set_motors_speed(0, 0);
    // if (time >= 600) {
    //   send_command(CMD_MOTOR_DISABLE, 0);
    // }
    set_state(STATE_RUNNING);
  }
}

static void opening_left(void) {
  uint32_t time = get_clock_ticks() - current_state_timer;
  if (time <= 70 || (time <= 140 && !is_rival_detected())) {
    set_motors_speed(-80, 80);
  } else {
    // set_motors_speed(0, 0);
    // if (time >= 600) {
    //   send_command(CMD_MOTOR_DISABLE, 0);
    // }
    set_state(STATE_RUNNING);
  }
}

static void opening_left_arc(void) {
  uint32_t time = get_clock_ticks() - current_state_timer;
  if (time <= 190 || (time <= 380 && !is_rival_detected())) {
    set_motors_speed(40, 90);
  } else if (time <= 190 + 120 || (time <= 380 + 240 && !is_rival_detected())) {
    set_motors_speed(80, -80);
  } else {
    // set_motors_speed(0, 0);
    // if (time >= 600) {
    //   send_command(CMD_MOTOR_DISABLE, 0);
    // }
    set_state(STATE_RUNNING);
  }
}

static void opening_back(void) {
  uint32_t time = get_clock_ticks() - current_state_timer;
  if (time <= 120 || (time <= 240 && !is_rival_detected())) {
    set_motors_speed(80, -80);
  } else {
    // set_motors_speed(0, 0);
    // if (time >= 800) {
    //   send_command(CMD_MOTOR_DISABLE, 0);
    // }
    set_state(STATE_RUNNING);
  }
}

/**
 * @brief Estrategia simple evitando salirse del dohyo, ignorando valor de sensores
 *
 */
static void strat_keeping_inside(void) {
  set_motors_speed(BASE_SPEED, BASE_SPEED);
  // printf("keeping inside\n");
  // set_motors_speed(10, 10);
  // La gestión de mantenerse en el dohyo se realiza por defecto mediante check_outter_line(void) y keeping_inside(void)
}

/**
 * @brief Estrategia que busca y persigue el rival, usando posición dinámica de sensores
 *
 */
static void strat_pid(void) {
  // TODO: quitar este if si se pasa la función principal a un ISR a 1ms
  if (get_clock_ticks() - strat_pid_last_ms > 1) {
    debug_sensors_leds();
    int16_t error = get_sensors_position();
    float correccion = error * STRAT_PID_KP + (error - strat_pid_last_error) * STRAT_PID_KD;

    strat_pid_last_error = error;
    // printf("%d | %d | ", error, correccion);
    set_motors_speed(BASE_SPEED + correccion, BASE_SPEED - correccion);
    strat_pid_last_ms = get_clock_ticks();

    // if (get_rival_close_ms() != 0) {
    //   uint32_t ms_diff = get_clock_ticks() - get_rival_close_ms();
    //   if (ms_diff > 250) {
    //     if (ms_diff < 1000) {
    //       // send_command(CMD_CONFIG_SINE_STEP, is_rival_close() ? 4 : 2);
    //     } else if (ms_diff < 1500) {
    //       // send_command(CMD_CONFIG_SINE_STEP, is_rival_close() ? 3 : 3);
    //     } else if (ms_diff < 2000) {
    //       // send_command(CMD_CONFIG_SINE_STEP, is_rival_close() ? 2 : 4);
    //     } else if (ms_diff < 2500) {
    //       // send_command(CMD_CONFIG_SINE_STEP, is_rival_close() ? 1 : 5);
    //     }
    //   }
    // }
  }
}

static void strat_steps(void) {
  if (get_clock_ticks() - strat_steps_last_ms > 5000) {
    uint32_t ms = get_clock_ticks();
    while (get_clock_ticks() - ms < 50) {
      set_motors_speed(BASE_SPEED, BASE_SPEED);
    }
    while (get_clock_ticks() - ms < 60) {
      set_motors_speed(0, 0);
    }
    strat_steps_count++;
    if (strat_steps_count >= 5) {
      set_strat(STRAT_PID);
    }
    strat_steps_last_ms = get_clock_ticks();
  }
  if (is_rival_close()) {
    set_strat(STRAT_PID);
  }
}

/**
 * @brief Comprueba si el robot está en funcionamiento
 *
 * @return bool
 */

bool is_competicion_iniciada(void) {
  return competicionIniciada;
}

/**
 * @brief Establece si la competición se ha iniciado y estado actual del robot
 *
 * @param iniciado Estado actual del robot
 */

void set_competicion_iniciada(bool iniciado) {
  competicionIniciada = iniciado;
  competicionIniciando = false;
  if (iniciado) {
    strat_steps_count = 0;
    strat_steps_last_ms = 0;
    set_state(STATE_OPENING);
  } else {
    send_command(CMD_MOTOR_DISABLE, 0);
  }
}

/**
 * @brief Comprueba si el robot está en funcionamiento
 *
 * @return bool
 */

bool is_competicion_iniciando(void) {
  return competicionIniciando;
}

/**
 * @brief Establece si la competición se ha iniciado y estado actual del robot
 *
 * @param iniciado Estado actual del robot
 */

void set_competicion_iniciando(bool iniciando) {
  competicionIniciando = iniciando;
}

/**
 * @brief Establece la estrategia de inicio
 *
 * @param OPENINGS opening
 */
void set_opening(enum OPENINGS opening) {
  current_opening = opening;
}

/**
 * @brief Obtiene la estrategia de inicio
 *
 * @param OPENINGS opening
 */
enum OPENINGS get_opening(void) {
  return current_opening;
}

/**
 * @brief Establece la estrategia actual
 *
 * @param STRATS strat
 */
void set_strat(enum STRATS strat) {
  current_strat = strat;
  current_strat_timer = get_clock_ticks();
}
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

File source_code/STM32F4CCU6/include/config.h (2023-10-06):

#ifndef __CONFIG_H
#define __CONFIG_H

#include <stdio.h>

#define SYSCLK_FREQUENCY_HZ 84000000
#define SYSTICK_FREQUENCY_HZ 1000
#define MICROSECONDS_PER_SECOND 1000000
#define PI 3.1415

#define MS_CALIBRACION_LINEA 2000
#define LECTURA_MAXIMO_SENSORES_LINEA 4096
#define LECTURA_MINIMO_SENSORES_LINEA 0

#define MOTORES_MAX_PWM 1023
#define LEDS_MAX_PWM 100//255

#define MILLIS_INICIO 5000


uint16_t get_start_millis(void);

#endif

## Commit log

2023-03-28 Actualiza timings y corrige gambada del index en la funcion `set_rgb`
    [leds.c, leds.h, main.c]
2023-03-28 Mejora nomenclatura de leds, ordena RGB y refactor general de comentarios sin uso
2023-03-30 Añade configuración de Timer de motores, cambia el Timer del RGB y añade gestión del botón de la placa
2023-04-01 Añade lectura de sensores
2023-04-07 Ajusta prioridades de timers y elimina el Builtin BTN
2023-04-07 Elimina el movimiento de motores al iniciar su timer
2023-04-07 Añade funciones de leds para `rainbow` y `loading`
2023-04-07 Añade funciones básicas de botones
2023-04-09 Actualiza prototipo de funciones de leds para usar enum
2023-04-09 Añade obtención individual de valor de sensor raw y calibrado
2023-04-09 Añade fichero de control y funciones de competición iniciada y main loop
2023-04-11 Añade gestión de motores y funciones útiles
2023-04-12 Actualiza índices de los sensores de rival y constantes
2023-04-12 Añade debug de sensores por RGB
2023-04-14 Corrige lógica de botones
    [buttons.c]
2023-04-14 Añade control de inicio de competición y prográma básico
2023-04-14 Añade función de leds para fatal_error
2023-04-14 Añade estructura de estrategias
2023-04-16 Añade gestión de Estados, Aperturas y Estrategias
2023-04-18 Simplifica la gestión de los motores
2023-04-18 Añade gestión de sensores inicial
2023-04-18 Actualiza gestión de motores
2023-04-18 Corrige errores de sensores y añade threshold máximo
    [sensors.c, sensors.h]
2023-04-30 Actualiza modelo3D y README y añade programa en Arduino Nano post-corto del STM32F4
2023-04-30 Mueve el programa del STM32F4 a una carpeta independiente
2023-08-24 Añade Pinout y proyecto KiCAD de la versión FOC
    [BlackPill_Main.kicad_sch, Bluepill_FOC.kicad_sch, UltiBot.kicad_pcb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]
2023-08-24 Actualiza diseño con los primeros cambios para FOC
2023-08-24 Añade código de Arduino pos-defunción del F4
2023-08-25 Añade pinout de BlackPill, completa esquemático y asocia footprints
    [BlackPill_Main.kicad_sch, Bluepill_FOC.kicad_sch, UltiBot.kicad_sch]
2023-08-25 Actualiza estructura del proyecto (symbols, footprints) y rutas relativas
    [BlackPill_Main.kicad_sch, Bluepill_FOC.kicad_sch]
2023-08-25 Añade info para las librerías de KiCAD
2023-08-25 Elimina el directorio de custom_libraries del repo
    Las librerías se gestionarán externamente desde https://github.com/OPRobots/KiCADLibraries y se incluirán en el proyecto local
2023-08-25 Limpia código del F4 y añade pruebas de SPI
2023-08-29 Añade pruebas de SPI
2023-08-29 Actualiza el esquemático de la PCB
    [BlackPill_Main.kicad_sch, Bluepill_FOC.kicad_sch, UltiBot.kicad_sch]
2023-08-29 Actualiza esquemático e inicia PCB
    [BlackPill_Main.kicad_sch, Bluepill_FOC.kicad_sch, UltiBot.kicad_pcb]
2023-08-31 Actualiza esquemático y finaliza ruteado de PCB
    [BlackPill_Main.kicad_sch, Bluepill_FOC.kicad_sch, UltiBot.kicad_pcb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]
2023-09-01 Termina el diseño del esquemático y PCB
    [BlackPill_Main.kicad_sch, Bluepill_FOC.kicad_sch, UltiBot.kicad_pcb]
2023-09-01 Añade los Gerbers de la primera versión de la PCB
    [UltiBot-B_Mask.gbr, UltiBot-B_Silkscreen.gbr, UltiBot-Back.gbr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]
2023-09-01 Añade imágenes de la PCB y actualiza README.md
2023-09-05 Añade inicio de comunicación por UART
2023-09-05 Elimina la variante ATmega328
2023-09-17 Acualiza Modelo 3D con PCB y chasis de prueba
2023-09-17 Actualiza estructura de gestión de comandos, mueve los .h a includes y añade submodule de OPRcontrolFOC
2023-09-22 Actualiza diseño y añade STLs
    [base.stl, motors.stl, top.stl]
2023-09-23 Actualiza el workspace
2023-09-23 Actualiza modelo 3D y añade STLs de rampa, apliador de rueda y espaciador
    [ramp.stl, spacer.stl, wheel.stl]
2023-09-23 Limpia referencias a SPI y actualiza gpios
2023-09-25 Añade debug de sensores por leds y corrige lectura de botones
    [buttons.c, leds.c, leds.h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]
2023-09-27 Añade configuración UART para comunicaciones simultáneas
2023-09-27 Añade funciones de control de leds
2023-09-28 Corrige cálculo de posición dinámico
    [sensors.c, sensors.h]
2023-09-28 Comenta el método de subida DFU
2023-09-28 Corrige fallo en la asignación de velocidad negativa
2023-09-28 Añade debugs de sensores y ajusta lectura de borde
2023-09-29 Añade filtro de sensores de media móvil y debug
2023-09-29 Refactor de sensores para mejora general
2023-09-29 Añade estrategia de seguimiento mediante PID
2023-10-01 Añade menú de configuración de estrategias y debug
2023-10-01 Añade movimientos de inicio y corrige el orden de los motores
    [control.c, main.c]
2023-10-02 Añade paso a STATE_RUNNING después de OPENING
2023-10-02 Mejora lectura de sensores y corrige bug en motores
    [control.c, sensors.h]
2023-10-05 Añade aceleraciones (incremento de torque)
2023-10-06 Añade OPENINGS en arco y algoritmo SITBAN
    Sistema de
    Incremento de
    Torque
    Basado en
    Aceleraciones
    Negativas
2023-12-20 Añade FOC en Closed Loop y elimina gestión de encoders
2024-02-23 Mejora general del robot · Ajusta sensibilidad de los sensores · Mejora los openings al usar FOC Closed Loop · Ajusta las constantes del PID para la STRAT_PID · Añade decoding de señal RC5 · Añade gu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
2024-02-23 Actualiza modelo 3D, STL y librerías KiCad
    [base.stl, ramp.stl, spacer.stl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]
2024-04-04 Añade opción de arranque enviando 1 y 2 desde cualquier ADDR
2024-04-24 Añade estrategia de pasitos y cambios para GranaBOT
2024-04-24 Actualiza control de FOC (buggy)
2024-10-09 Ajusta el control de las estrategias y aperturas
2024-10-11 Añade modelo 3D y stl de la nueva versión y actualiza el submodule del FOC
    [base_v2.stl, molde_plomo.stl, ramp_v2.stl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]
2025-02-27 Añade gestión de configuraciones desde IRStart
